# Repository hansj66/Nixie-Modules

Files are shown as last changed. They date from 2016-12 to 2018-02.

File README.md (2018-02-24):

This repository holds a Collection of Eagle schematics and board layouts for driving Nixie and VFD display tubes.
These schematics are not yet verified. The IN-12 Arduino and Raspberry Shields are tested ok. The remaining modules are still in development.

# IN-12-Raspberry Pi Zero W Shield

This is a 6 tube shield that connects to the GPIO header of a Raspberry Pi Zero W. 

IN12 RaspberryShield1

IN12 RaspberryShield2

IN12 RaspberryShield3

A video of the shield running the clock.c driver can be found here: https://youtu.be/0auW9YwZaXU

# IN-12-Arduino Shield 

IN12Shield1

IN12Shield2

A video of the shield running the code sample can be found here: https://youtu.be/qcBPYD-F15M

The shield has 4 IN-12 Nixie tubes. The shield requires external 170V power. 5V is obtained via the shield connector. Pin mapping is as follows

## Parts list:

- 4 x IN-12 tubes.
- 4 x K155ID1.
- 2 x 74HC595.
- 4 x anode resistors. The value of these should be calculated according to tube rating and drive voltage.
- 5 x pushbutton switches (optional).  

### Arduino pin mapping
- D0: SER
- D1: RCLK
- D2: SER
- D8-D12: optional switches.  

# IN-2 Nixie-Modules
Each Module has two Nixie tubes, a shift register and a nixie driver. The modules require external 5V/170V power. The on-board shift registeres allows the modules to be daisy chained.  

## Parts list:
- 2 x IN-2 tubes.
- 2 x K155ID1.
- 1 x 74HC595.
- 2 x anode resistors. The value of these should be calculated according to tube rating and drive voltage.  

IN2Modules

IN2Modules_individual

IN2Modules_assembled

# TimeExpander Eagle Library
The librar contains Eagle symbol, package and device definitions for K155ID1 (pin compatible with the obsolete 74141) along with the following display tubes:  
- IN-1 - not verified
- IN-2 - verified
- IN-12 - verified
- IV-12 - not verified
- IV-22 - not verified

# IN-1-Modules
TBD

# VFD-Modules
TBD



Hans Jørgen Grimstad
www.TimeExpander.com

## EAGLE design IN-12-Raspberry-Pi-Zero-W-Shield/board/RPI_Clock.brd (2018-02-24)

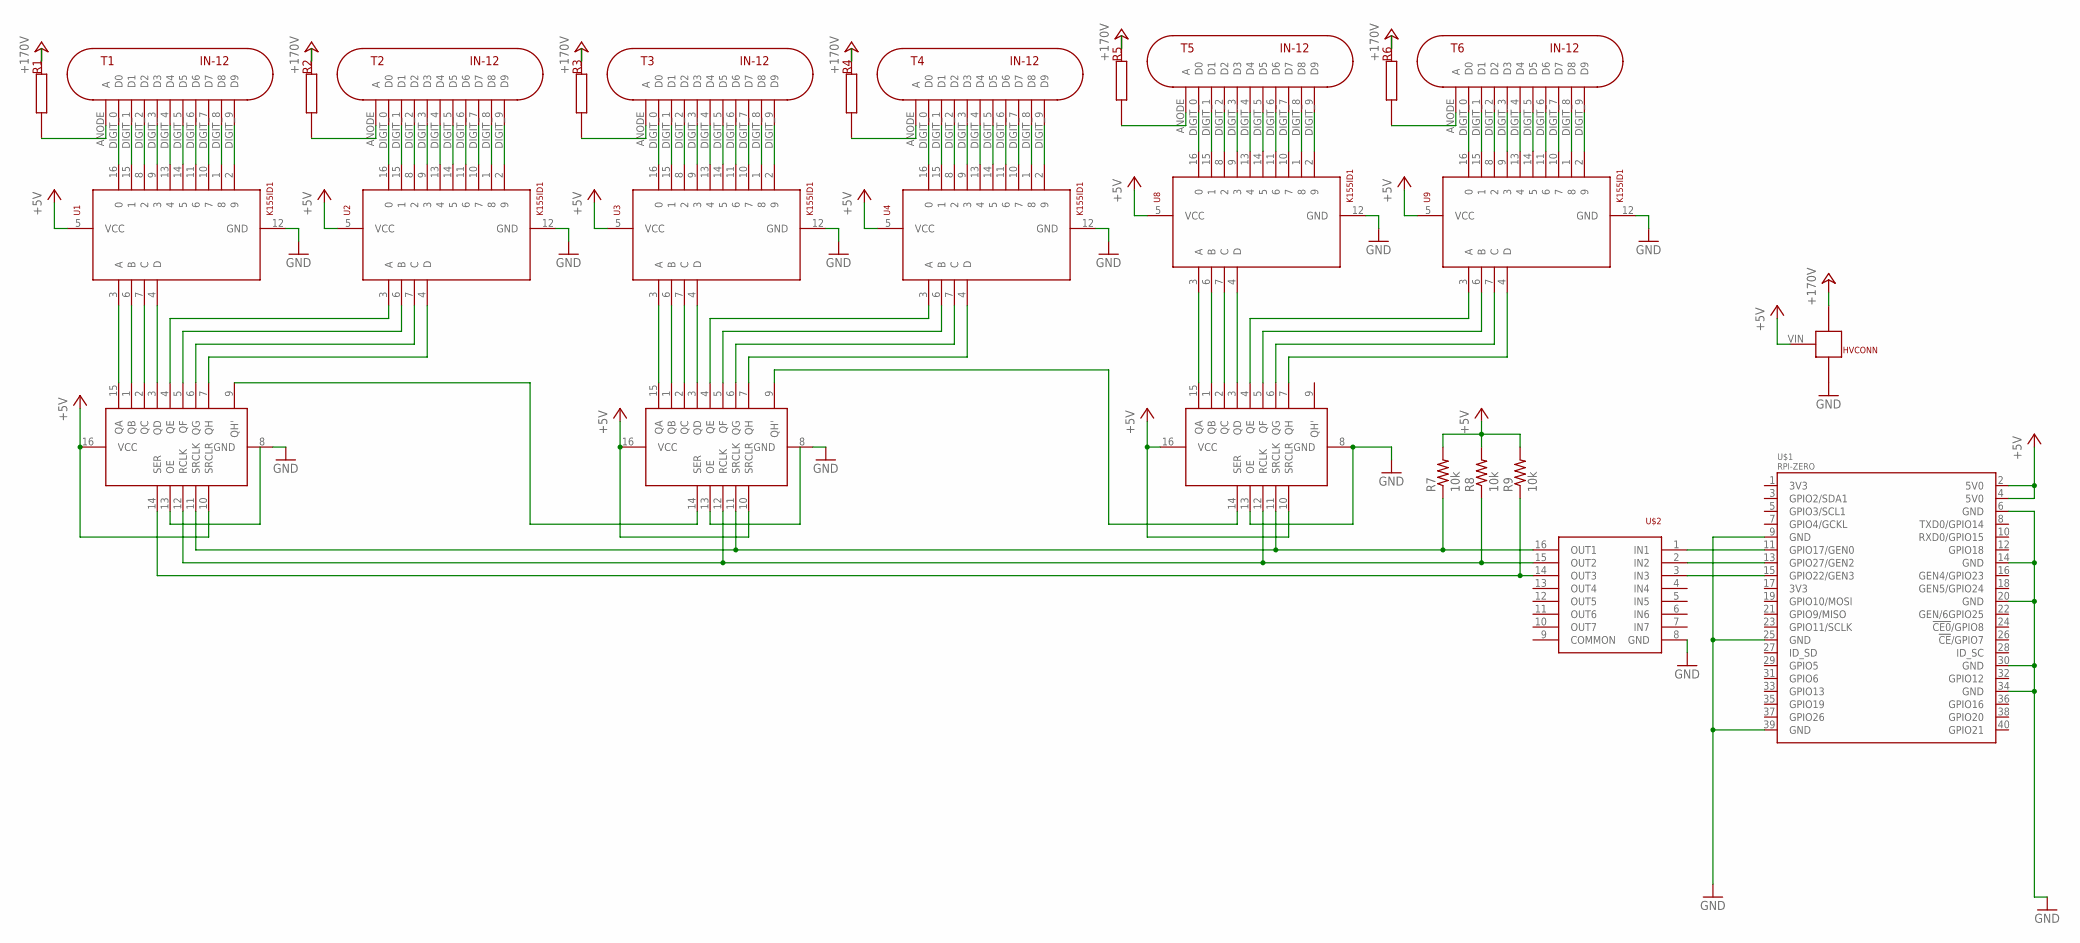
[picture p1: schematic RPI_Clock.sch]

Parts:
HVCONN: HV_CONNECTOR
R1, R2, R3, R4, R5, R6: 5,6K; ANODE_RESISTOR
R7, R8, R9: 10k; 0805
T1, T2, T3, T4, T5, T6: IN-12
U1, U2, U3, U4, U8, U9: K155ID1; DIP16-2.54-19.2X7.62MM
U6, U7, U11: 74HC595; DIL16
U$1: RPI-ZERO; RASP_PI_ZERO_BOARD_FULL
U$2: ULN2003D1013TR; SO16-NARROW

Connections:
+5V: HVCONN.VIN, R7.2, R8.2, R9.2, U1.5 (VCC), U2.5 (VCC), U3.5 (VCC), U4.5 (VCC), U6.10 (SRCLR), U6.16 (VCC), U7.10 (SRCLR), U7.16 (VCC), U8.5 (VCC), U9.5 (VCC), U11.10 (SRCLR), U11.16 (VCC), U$1.2 (5V0), U$1.4 (5V0)
+24V: HVCONN.+170V, R1.P$2, R2.P$2, R3.P$2, R4.P$2, R5.P$2, R6.P$2
GND: HVCONN.GND, U1.12 (GND), U2.12 (GND), U3.12 (GND), U4.12 (GND), U6.8 (GND), U7.8 (GND), U8.12 (GND), U9.12 (GND), U11.8 (GND), U11.13 (OE), U$1.6 (GND), U$1.9 (GND), U$1.14 (GND), U$1.20 (GND), U$1.25 (GND), U$1.30 (GND), U$1.34 (GND), U$1.39 (GND), U$2.8 (GND)
unnamed: T1.DIGIT_9 (D9), U1.2 (9)
unnamed: T1.DIGIT_8 (D8), U1.1 (8)
unnamed: T1.DIGIT_7 (D7), U1.10 (7)
unnamed: T1.DIGIT_6 (D6), U1.11 (6)
unnamed: T1.DIGIT_5 (D5), U1.14 (5)
unnamed: T1.DIGIT_4 (D4), U1.13 (4)
unnamed: T1.DIGIT_3 (D3), U1.9 (3)
unnamed: T1.DIGIT_2 (D2), U1.8 (2)
unnamed: T1.DIGIT_1 (D1), U1.15 (1)
unnamed: T1.DIGIT_0 (D0), U1.16 (0)
unnamed: R1.P$1, T1.ANODE (A)
unnamed: T2.DIGIT_9 (D9), U2.2 (9)
unnamed: T2.DIGIT_8 (D8), U2.1 (8)
unnamed: T2.DIGIT_7 (D7), U2.10 (7)
unnamed: T2.DIGIT_6 (D6), U2.11 (6)
unnamed: T2.DIGIT_5 (D5), U2.14 (5)
unnamed: T2.DIGIT_4 (D4), U2.13 (4)
unnamed: T2.DIGIT_3 (D3), U2.9 (3)
unnamed: T2.DIGIT_2 (D2), U2.8 (2)
unnamed: T2.DIGIT_1 (D1), U2.15 (1)
unnamed: T2.DIGIT_0 (D0), U2.16 (0)
unnamed: R2.P$1, T2.ANODE (A)
unnamed: T3.DIGIT_9 (D9), U3.2 (9)
unnamed: T3.DIGIT_8 (D8), U3.1 (8)
unnamed: T3.DIGIT_7 (D7), U3.10 (7)
unnamed: T3.DIGIT_6 (D6), U3.11 (6)
unnamed: T3.DIGIT_5 (D5), U3.14 (5)
unnamed: T3.DIGIT_4 (D4), U3.13 (4)
unnamed: T3.DIGIT_3 (D3), U3.9 (3)
unnamed: T3.DIGIT_2 (D2), U3.8 (2)
unnamed: T3.DIGIT_1 (D1), U3.15 (1)
unnamed: T3.DIGIT_0 (D0), U3.16 (0)
unnamed: R3.P$1, T3.ANODE (A)
unnamed: T4.DIGIT_9 (D9), U4.2 (9)
unnamed: T4.DIGIT_8 (D8), U4.1 (8)
unnamed: T4.DIGIT_7 (D7), U4.10 (7)
unnamed: T4.DIGIT_6 (D6), U4.11 (6)
unnamed: T4.DIGIT_5 (D5), U4.14 (5)
unnamed: T4.DIGIT_4 (D4), U4.13 (4)
unnamed: T4.DIGIT_3 (D3), U4.9 (3)
unnamed: T4.DIGIT_2 (D2), U4.8 (2)
unnamed: T4.DIGIT_1 (D1), U4.15 (1)
unnamed: T4.DIGIT_0 (D0), U4.16 (0)
unnamed: R4.P$1, T4.ANODE (A)
unnamed: U$1.11 (GPIO17/GEN0), U$2.1 (IN1)
unnamed: U$1.13 (GPIO27/GEN2), U$2.2 (IN2)
unnamed: R7.1, U6.11 (SRCLK), U7.11 (SRCLK), U11.11 (SRCLK), U$2.16 (OUT1)
unnamed: R8.1, U6.12 (RCLK), U7.12 (RCLK), U11.12 (RCLK), U$2.15 (OUT2)
unnamed: R9.1, U6.14 (SER), U$2.14 (OUT3)
unnamed: U$1.15 (GPIO22/GEN3), U$2.3 (IN3)
unnamed: T5.DIGIT_9 (D9), U8.2 (9)
unnamed: T5.DIGIT_8 (D8), U8.1 (8)
unnamed: T5.DIGIT_7 (D7), U8.10 (7)
unnamed: T5.DIGIT_6 (D6), U8.11 (6)
unnamed: T5.DIGIT_5 (D5), U8.14 (5)
unnamed: T5.DIGIT_4 (D4), U8.13 (4)
unnamed: T5.DIGIT_3 (D3), U8.9 (3)
unnamed: T5.DIGIT_2 (D2), U8.8 (2)
unnamed: T5.DIGIT_1 (D1), U8.15 (1)
unnamed: T5.DIGIT_0 (D0), U8.16 (0)
unnamed: R5.P$1, T5.ANODE (A)
unnamed: U1.3 (A), U6.15 (QA)
unnamed: U1.6 (B), U6.1 (QB)
unnamed: U1.7 (C), U6.2 (QC)
unnamed: U1.4 (D), U6.3 (QD)
unnamed: U2.3 (A), U6.4 (QE)
unnamed: U2.6 (B), U6.5 (QF)
unnamed: U2.7 (C), U6.6 (QG)
unnamed: U2.4 (D), U6.7 (QH)
unnamed: U3.3 (A), U7.15 (QA)
unnamed: U3.6 (B), U7.1 (QB)
unnamed: U3.7 (C), U7.2 (QC)
unnamed: U3.4 (D), U7.3 (QD)
unnamed: U4.3 (A), U7.4 (QE)
unnamed: U4.6 (B), U7.5 (QF)
unnamed: U4.7 (C), U7.6 (QG)
unnamed: U4.4 (D), U7.7 (QH)
unnamed: T6.DIGIT_9 (D9), U9.2 (9)
unnamed: T6.DIGIT_8 (D8), U9.1 (8)
unnamed: T6.DIGIT_7 (D7), U9.10 (7)
unnamed: T6.DIGIT_6 (D6), U9.11 (6)
unnamed: T6.DIGIT_5 (D5), U9.14 (5)
unnamed: T6.DIGIT_4 (D4), U9.13 (4)
unnamed: T6.DIGIT_3 (D3), U9.9 (3)
unnamed: T6.DIGIT_2 (D2), U9.8 (2)
unnamed: U6.9 (QH'), U7.14 (SER)
unnamed: T6.DIGIT_1 (D1), U9.15 (1)
unnamed: T6.DIGIT_0 (D0), U9.16 (0)
unnamed: R6.P$1, T6.ANODE (A)
unnamed: U8.3 (A), U11.15 (QA)
unnamed: U8.6 (B), U11.1 (QB)
unnamed: U8.7 (C), U11.2 (QC)
unnamed: U8.4 (D), U11.3 (QD)
unnamed: U9.3 (A), U11.4 (QE)
unnamed: U9.6 (B), U11.5 (QF)
unnamed: U9.7 (C), U11.6 (QG)
unnamed: U9.4 (D), U11.7 (QH)
unnamed: U7.9 (QH'), U11.14 (SER)

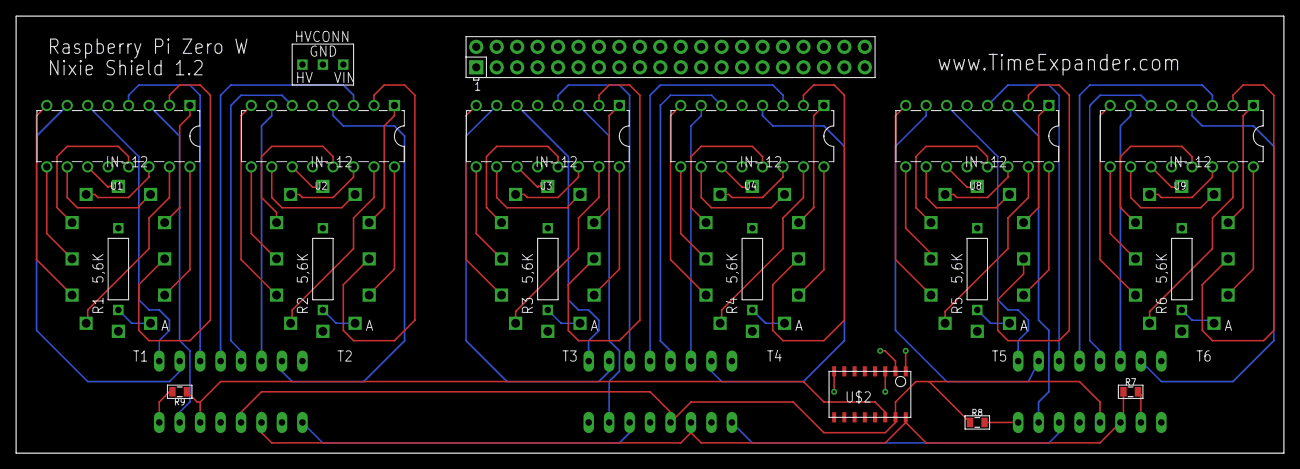
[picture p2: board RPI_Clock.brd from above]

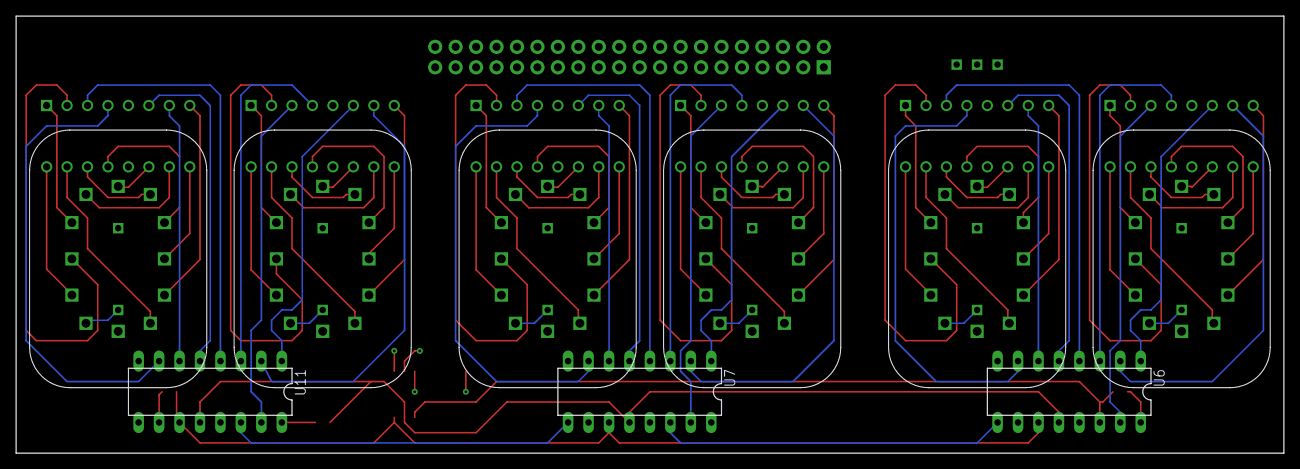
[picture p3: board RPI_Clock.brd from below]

Board: 4 copper layers, 157.5 x 54.3 mm, 27 parts (3 on the bottom side), 101 nets.

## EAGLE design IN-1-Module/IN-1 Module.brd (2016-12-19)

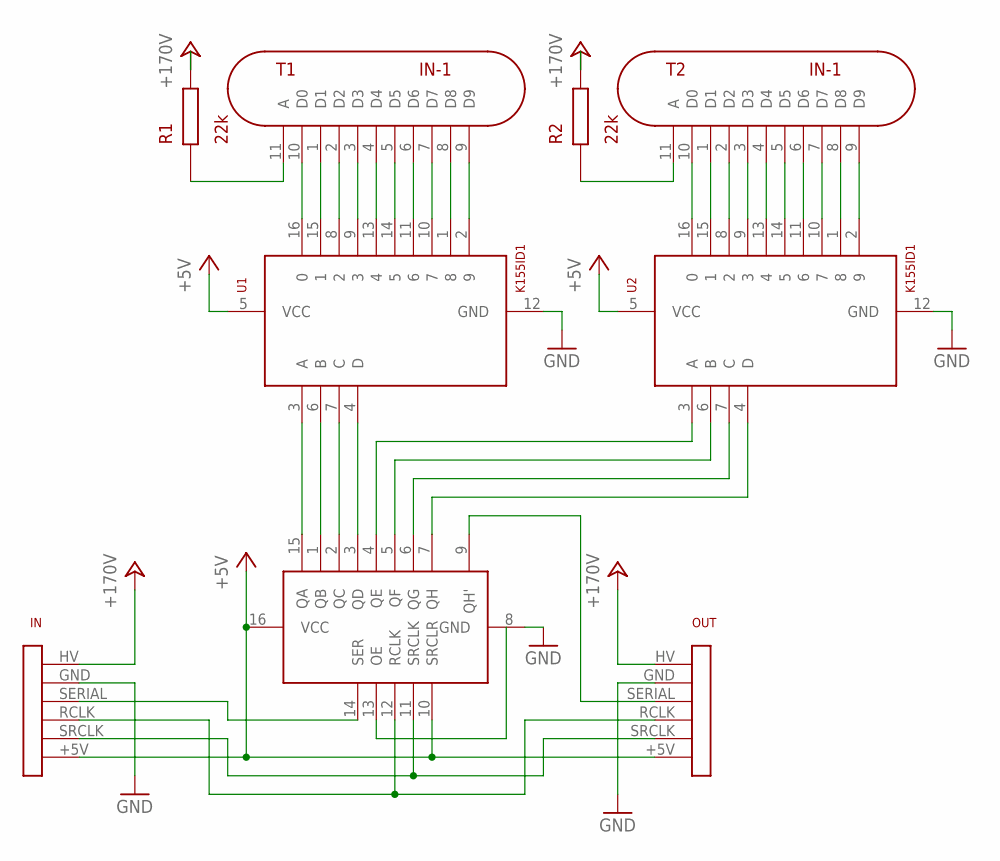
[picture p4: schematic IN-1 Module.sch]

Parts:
IN: NIXIE_INTERCONNECT
OUT: NIXIE_INTERCONNECT
R1, R2: 22k; ANODE_RESISTOR
T1, T2: IN-1
U1, U2: K155ID1; DIP16-2.54-19.2X7.62MM
U3: 74HC595; DIL16

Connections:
+5V: IN.+5V, OUT.+5V, U1.5 (VCC), U2.5 (VCC), U3.10 (SRCLR), U3.16 (VCC)
+24V: IN.HV, OUT.HV, R1.P$2, R2.P$2
GND: IN.GND, OUT.GND, U1.12 (GND), U2.12 (GND), U3.8 (GND)
unnamed: R1.P$1, T1.11 (A)
unnamed: T1.10 (D0), U1.16 (0)
unnamed: T1.1 (D1), U1.15 (1)
unnamed: T1.2 (D2), U1.8 (2)
unnamed: T1.3 (D3), U1.9 (3)
unnamed: T1.4 (D4), U1.13 (4)
unnamed: T1.5 (D5), U1.14 (5)
unnamed: T1.6 (D6), U1.11 (6)
unnamed: T1.7 (D7), U1.10 (7)
unnamed: T1.8 (D8), U1.1 (8)
unnamed: T1.9 (D9), U1.2 (9)
unnamed: R2.P$1, T2.11 (A)
unnamed: T2.10 (D0), U2.16 (0)
unnamed: T2.1 (D1), U2.15 (1)
unnamed: T2.2 (D2), U2.8 (2)
unnamed: T2.3 (D3), U2.9 (3)
unnamed: T2.4 (D4), U2.13 (4)
unnamed: T2.5 (D5), U2.14 (5)
unnamed: T2.6 (D6), U2.11 (6)
unnamed: T2.7 (D7), U2.10 (7)
unnamed: T2.8 (D8), U2.1 (8)
unnamed: T2.9 (D9), U2.2 (9)
unnamed: OUT.SERIAL, U3.9 (QH')
unnamed: IN.SERIAL, U3.14 (SER)
unnamed: IN.RCLK, OUT.RCLK, U3.12 (RCLK)
unnamed: IN.SRCLK, OUT.SRCLK, U3.11 (SRCLK)
unnamed: U1.3 (A), U3.15 (QA)
unnamed: U1.6 (B), U3.1 (QB)
unnamed: U1.7 (C), U3.2 (QC)
unnamed: U1.4 (D), U3.3 (QD)
unnamed: U2.3 (A), U3.4 (QE)
unnamed: U2.6 (B), U3.5 (QF)
unnamed: U2.7 (C), U3.6 (QG)
unnamed: U2.4 (D), U3.7 (QH)

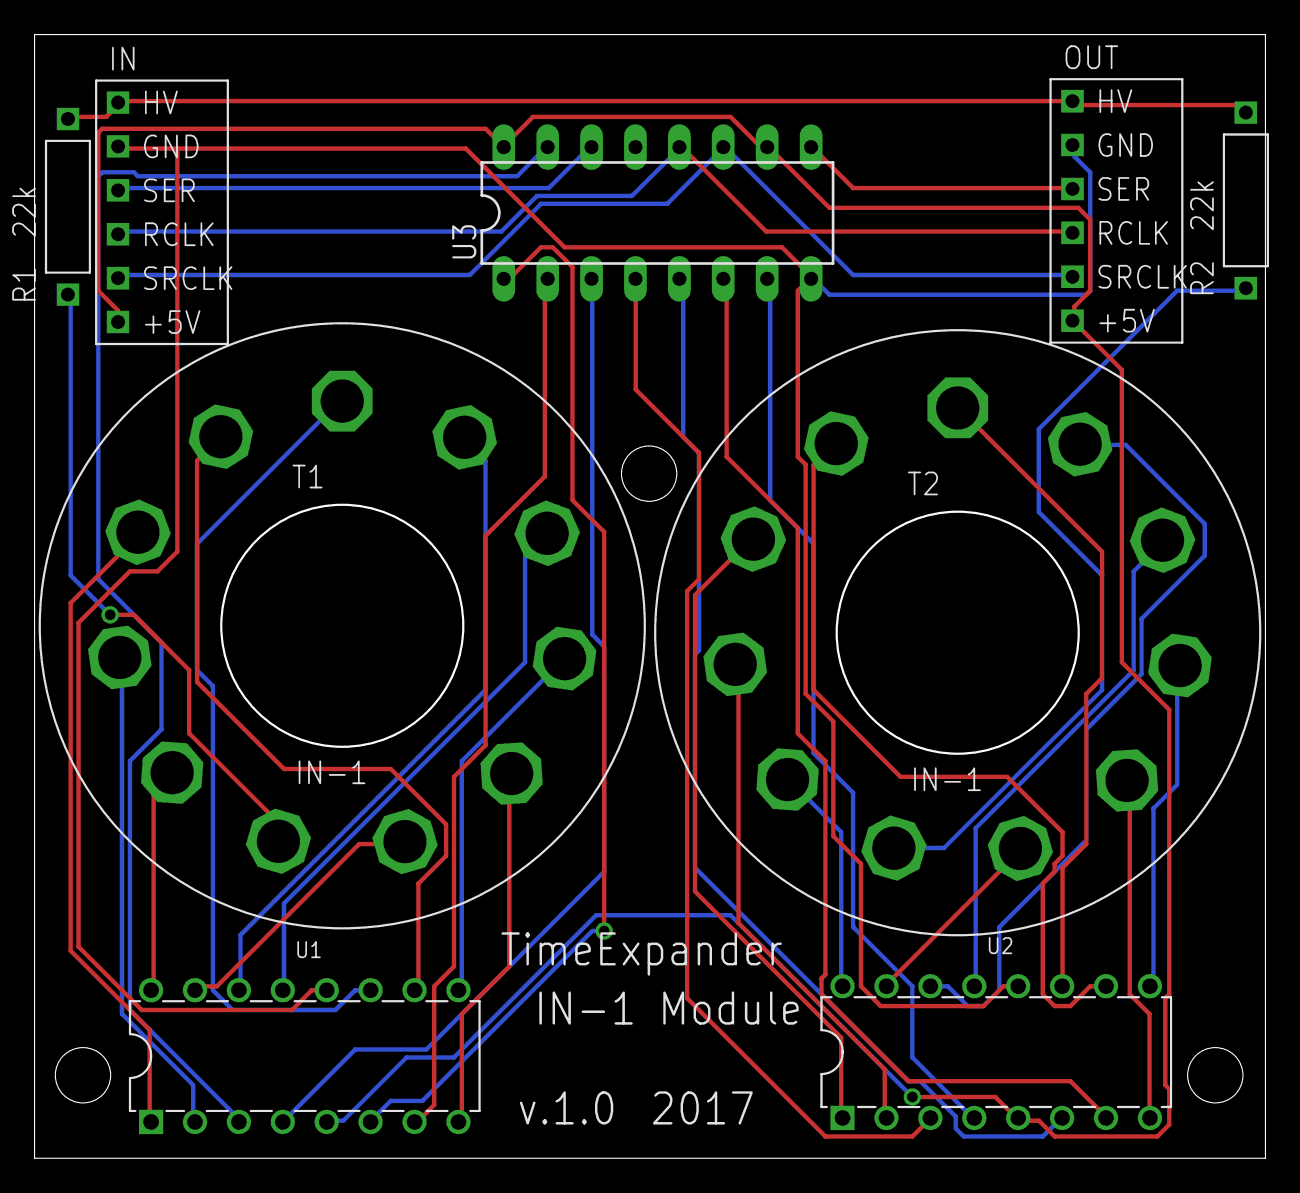
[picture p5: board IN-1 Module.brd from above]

Board: 2 copper layers, 71.2 x 65.0 mm, 9 parts (0 on the bottom side), 37 nets.

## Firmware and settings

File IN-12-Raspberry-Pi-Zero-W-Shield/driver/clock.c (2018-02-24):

#include <unistd.h>
#include <wiringPi.h>
#include <sr595.h>
#include <stdio.h>
#include <time.h>
#include <sys/time.h>

// 74HC595 pinout
// pin 14: SER/DS
// pin 12: RCLK/STCP
// pin 11: SRCLK/SHCP

#define SRCLK 0 // GPIO 17
#define RCLK 2 // GPIO 27
#define SER 3 // GPIO 22

#define BASE_PIN 100
#define NUM_PINS 24
#define NUM_DIGITS 6
#define K155ID1_INPUTS 4 

unsigned char DIGIT[10][K155ID1_INPUTS] = {
{0,0,0,0},
{1,0,0,0},
{0,1,0,0},
{1,1,0,0},
{0,0,1,0},
{1,0,1,0},
{0,1,1,0},
{1,1,1,0},
{0,0,0,1},
{1,0,0,1}
};

unsigned char BUFFER[NUM_DIGITS*K155ID1_INPUTS] = {
0,0,0,0,
0,0,0,0,
0,0,0,0,
0,0,0,0,
0,0,0,0,
0,0,0,0,
};


void testDigit(int pos, int value)
{
	digitalWrite(pos++, DIGIT[value][0]);
	digitalWrite(pos++, DIGIT[value][1]);
	digitalWrite(pos++, DIGIT[value][2]);
	digitalWrite(pos++, DIGIT[value][3]);
}


void mapTimeToBuffer(int rmdr)
{
	int dvsr;
	int quot;
    	dvsr = 100000;
    
	int index = 0;	
	while(dvsr)
	{                     
        	quot = rmdr / dvsr;
         	BUFFER[index] = DIGIT[quot][0];
         	BUFFER[index+1] = DIGIT[quot][1];
         	BUFFER[index+2] = DIGIT[quot][2];
         	BUFFER[index+3] = DIGIT[quot][3];
		index += 4;		
		rmdr %= dvsr;
        	dvsr /= 10;
    	}
}

int main(void)
{
	wiringPiSetup();
 	sr595Setup (BASE_PIN, NUM_PINS, SER, SRCLK, RCLK);
	int base = BASE_PIN;

	for (int number=0; number < 999999; number++)
	{	
		struct timeval tv;
 		struct tm* ptm;
 		gettimeofday (&tv, NULL);
 		ptm = localtime (&tv.tv_sec);

		mapTimeToBuffer((ptm->tm_hour+1)*10000+ptm->tm_min*100+ptm->tm_sec);
		for (int i=0; i<NUM_DIGITS*K155ID1_INPUTS; i++)
		{
			digitalWrite(base+i, BUFFER[i]);
		
			delay(2);
		}
	}	
	return 0;
}

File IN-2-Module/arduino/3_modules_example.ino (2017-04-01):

int SRCLK_Pin = 0; // SRCLK
int RCLK_Pin = 1; // RCLK
int SER_Pin = 2; // SER


#define shift_registers 3 
#define numOfRegisterPins shift_registers * 8

boolean registers[numOfRegisterPins];

// K155ID1      // 74HC595
// D C B A      A B C D 
// 0 0 0 0  0   0 0 0 0
// 0 0 0 1  1   1 0 0 0
// 0 0 1 0  2   0 1 0 0
// 0 0 1 1  3   1 1 0 0
// 0 1 0 0  4   0 0 1 0
// 0 1 0 1  5   1 0 1 0
// 0 1 1 0  6   0 1 1 0
// 0 1 1 1  7   1 1 1 0
// 1 0 0 0  8   0 0 0 1
// 1 0 0 1  9   1 0 0 1

byte leds = 0;

boolean digits[10][16] = {
0,0,0,0, 0,0,0,0, 0,0,0,0, 0,0,0,0, // 0 
1,0,0,0, 1,0,0,0, 1,0,0,0, 1,0,0,0, // 1
0,1,0,0, 0,1,0,0, 0,1,0,0, 0,1,0,0, // 2 
1,1,0,0, 1,1,0,0, 1,1,0,0, 1,1,0,0, // 3 
0,0,1,0, 0,0,1,0, 0,0,1,0, 0,0,1,0, // 4 
1,0,1,0, 1,0,1,0, 1,0,1,0, 1,0,1,0, // 5
0,1,1,0, 0,1,1,0, 0,1,1,0, 0,1,1,0, // 6
1,1,1,0, 1,1,1,0, 1,1,1,0, 1,1,1,0, // 7 
0,0,0,1, 0,0,0,1, 0,0,0,1, 0,0,0,1, // 8
1,0,0,1, 1,0,0,1, 1,0,0,1, 1,0,0,1, // 9
};

boolean banner[11][24] = {
0,0,0,0, 1,0,0,0, 0,1,0,0, 1,1,0,0, 0,0,1,0, 1,0,1,0,
1,0,0,0, 0,1,0,0, 1,1,0,0, 0,0,1,0, 1,0,1,0, 0,1,1,0,
0,1,0,0, 1,1,0,0, 0,0,1,0, 1,0,1,0, 0,1,1,0, 1,1,1,0, 
1,1,0,0, 0,0,1,0, 1,0,1,0, 0,1,1,0, 1,1,1,0, 0,0,0,1,
0,0,1,0, 1,0,1,0, 0,1,1,0, 1,1,1,0, 0,0,0,1, 1,0,0,1, 
1,0,1,0, 0,1,1,0, 1,1,1,0, 0,0,0,1, 1,0,0,1, 0,0,0,0, 
0,1,1,0, 1,1,1,0, 0,0,0,1, 1,0,0,1, 0,0,0,0, 0,0,0,0, 
1,1,1,0, 0,0,0,1, 1,0,0,1, 0,0,0,0, 0,0,0,0, 0,0,0,0, 
0,0,0,1, 1,0,0,1, 0,0,0,0, 0,0,0,0, 0,0,0,0, 0,0,0,0,
1,0,0,1, 0,0,0,0, 0,0,0,0, 0,0,0,0, 0,0,0,0, 0,0,0,0,
0,0,0,0, 0,0,0,0, 0,0,0,0, 0,0,0,0, 0,0,0,0, 0,0,0,0,
};

void setup() 
{
  pinMode(SER_Pin, OUTPUT);
  pinMode(RCLK_Pin, OUTPUT);
  pinMode(SRCLK_Pin, OUTPUT);
}


//set all register pins to LOW
void clearRegisters(){
  for(int i = numOfRegisterPins - 1; i >=  0; i--)
  {
     registers[i] = LOW;
  }
} 

//Set and display registers
void writeRegisters(){

  digitalWrite(RCLK_Pin, LOW);

  for(int i = numOfRegisterPins - 1; i >=  0; i--)
  {
    digitalWrite(SRCLK_Pin, LOW);
    bool val = registers[i];
    digitalWrite(SER_Pin, val);
    digitalWrite(SRCLK_Pin, HIGH);
  }
  digitalWrite(RCLK_Pin, HIGH);
}

//set an individual pin HIGH or LOW
void setRegisterPin(int index, int value)
{
  registers[index] = value;
}


void loop()
{
  for (int d=0; d<11; d++) 
  {
    for (int i=23; i>=0; i--)
    {
      if (banner[d][i] == 1) {
        setRegisterPin(i, HIGH);
      } else {
        setRegisterPin(i, LOW);
      }
    }
    writeRegisters(); 
    delay (500);
  }

}

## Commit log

2016-12-19 Added IN-12 shield, IN-1/2/12 Module, Eagle Library
    [IN-1 Module.brd, IN-1 Module.sch, IN-12 Module.brd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]
2017-02-15 Fixed tube orientation. Added firmware example code.
    [IN-12-Arduino-Shield.brd, IN-12-Arduino-Shield.sch]
2017-03-19 Updated interconnect package.
    [IN-2-Module.sch]
2017-04-01 Added arduino example for IN-2 modules
2018-02-24 Added driver code for Raspberry Pi Zero W shield
2018-02-24 Added Eagle sch/brd and BoM for raspberry clock
    [RPI_Clock.brd, RPI_Clock.sch]

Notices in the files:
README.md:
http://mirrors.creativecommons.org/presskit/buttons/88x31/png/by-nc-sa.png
